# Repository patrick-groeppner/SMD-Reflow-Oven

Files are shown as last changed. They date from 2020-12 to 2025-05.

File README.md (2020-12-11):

# SMD-Reflow-Oven
files and pictures for the selfmade SMD reflow oven. Made with an Arduino as a PID controller, a thermocouple sensor for fast and high range measurements and a solid state relay for switching an mini oven on and off

capable of:
- reflow soldering with different profiles / manual set temperature
- heating pcb clads with photoresist lacquer: temp curve and manual set temperature

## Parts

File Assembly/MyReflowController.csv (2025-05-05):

Designator | Quantity | Comment | Footprint | LCSC Part #
C1, C2, C4, C6, C8, C12, C13, C15, C16, C18, | 10 | 100nF | 0603 | C14663
C3, | 1 | 1uF | 0805 | C28323
C5, | 1 | 30pF | 0603 | C22397
C7, C10, | 2 | 10nF | 0603 | C57112
C9, | 1 | 30pF | 0603 | C22397
C11, C14, | 2 | 10uF | 0805 | C15850
C17, | 1 | 100nF | 0805 | C14663
D1, | 1 | Red | 0805 | C84256
D2, D3, | 2 | Green | 0603 | C72043
FB1, | 1 | Ferrit | 0805 | C1017
Q1, | 1 | SS8050 | SOT-23-3 | C2150
Q2, Q3, | 2 | AO3400A | SOT-23-3L | C20917
R1, R2, | 2 | 2K2 | 0603 | C4190
R3, R4, R6, R12, | 4 | 10k | 0805 | C17414
R5, | 1 | 100R | 1206 | C17901
R7, R8, R9, | 3 | 10K | 1206 | C17902
R10, R11, R15, | 3 | 1K | 0603 | C21190
R13, R14, | 2 | 100R | 0603 | C22775
U1, | 1 | ATMEGA328P | TQFP-32_7.0x7.0x0.8P | C14877
U2, | 1 | MAX6675 | SOIC-8_3.9x4.9x1.27P | C16030
U3, | 1 | AMS1117-3.3 | SOT-223 | C6186
U4, | 1 | CH340E | MSOP-10_3.0x3.0x0.5P | C99652
Y1, | 1 | 8MHz | SMD-5032_2P | C115962

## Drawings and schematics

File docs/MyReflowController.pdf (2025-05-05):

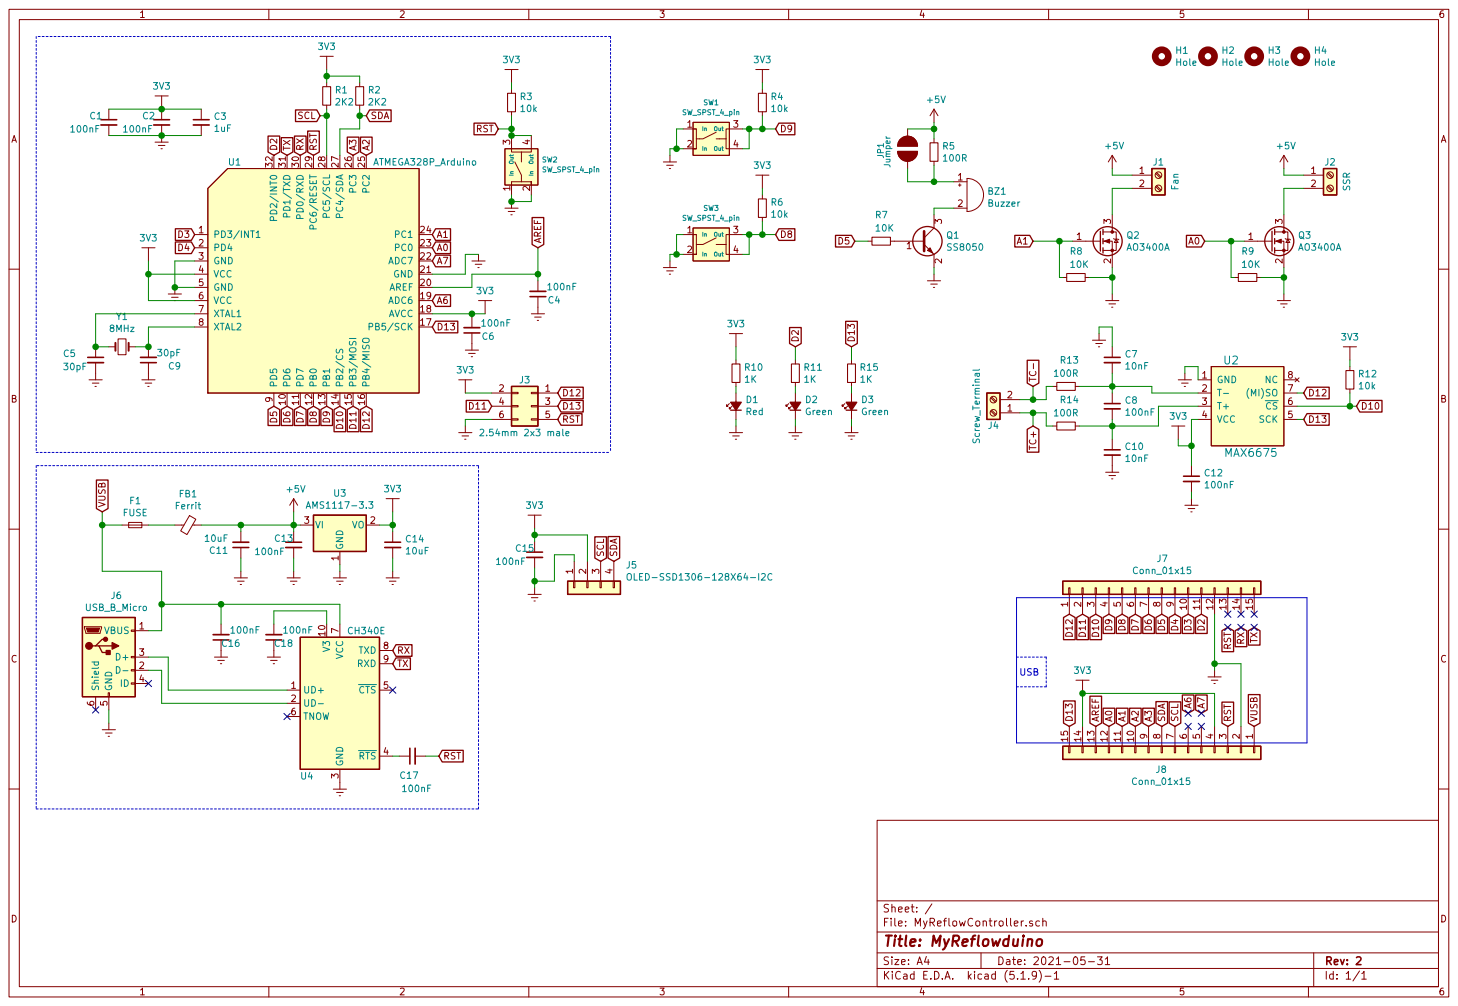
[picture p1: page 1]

3 RTS 4 CTS 5 TNOW 6 VCC

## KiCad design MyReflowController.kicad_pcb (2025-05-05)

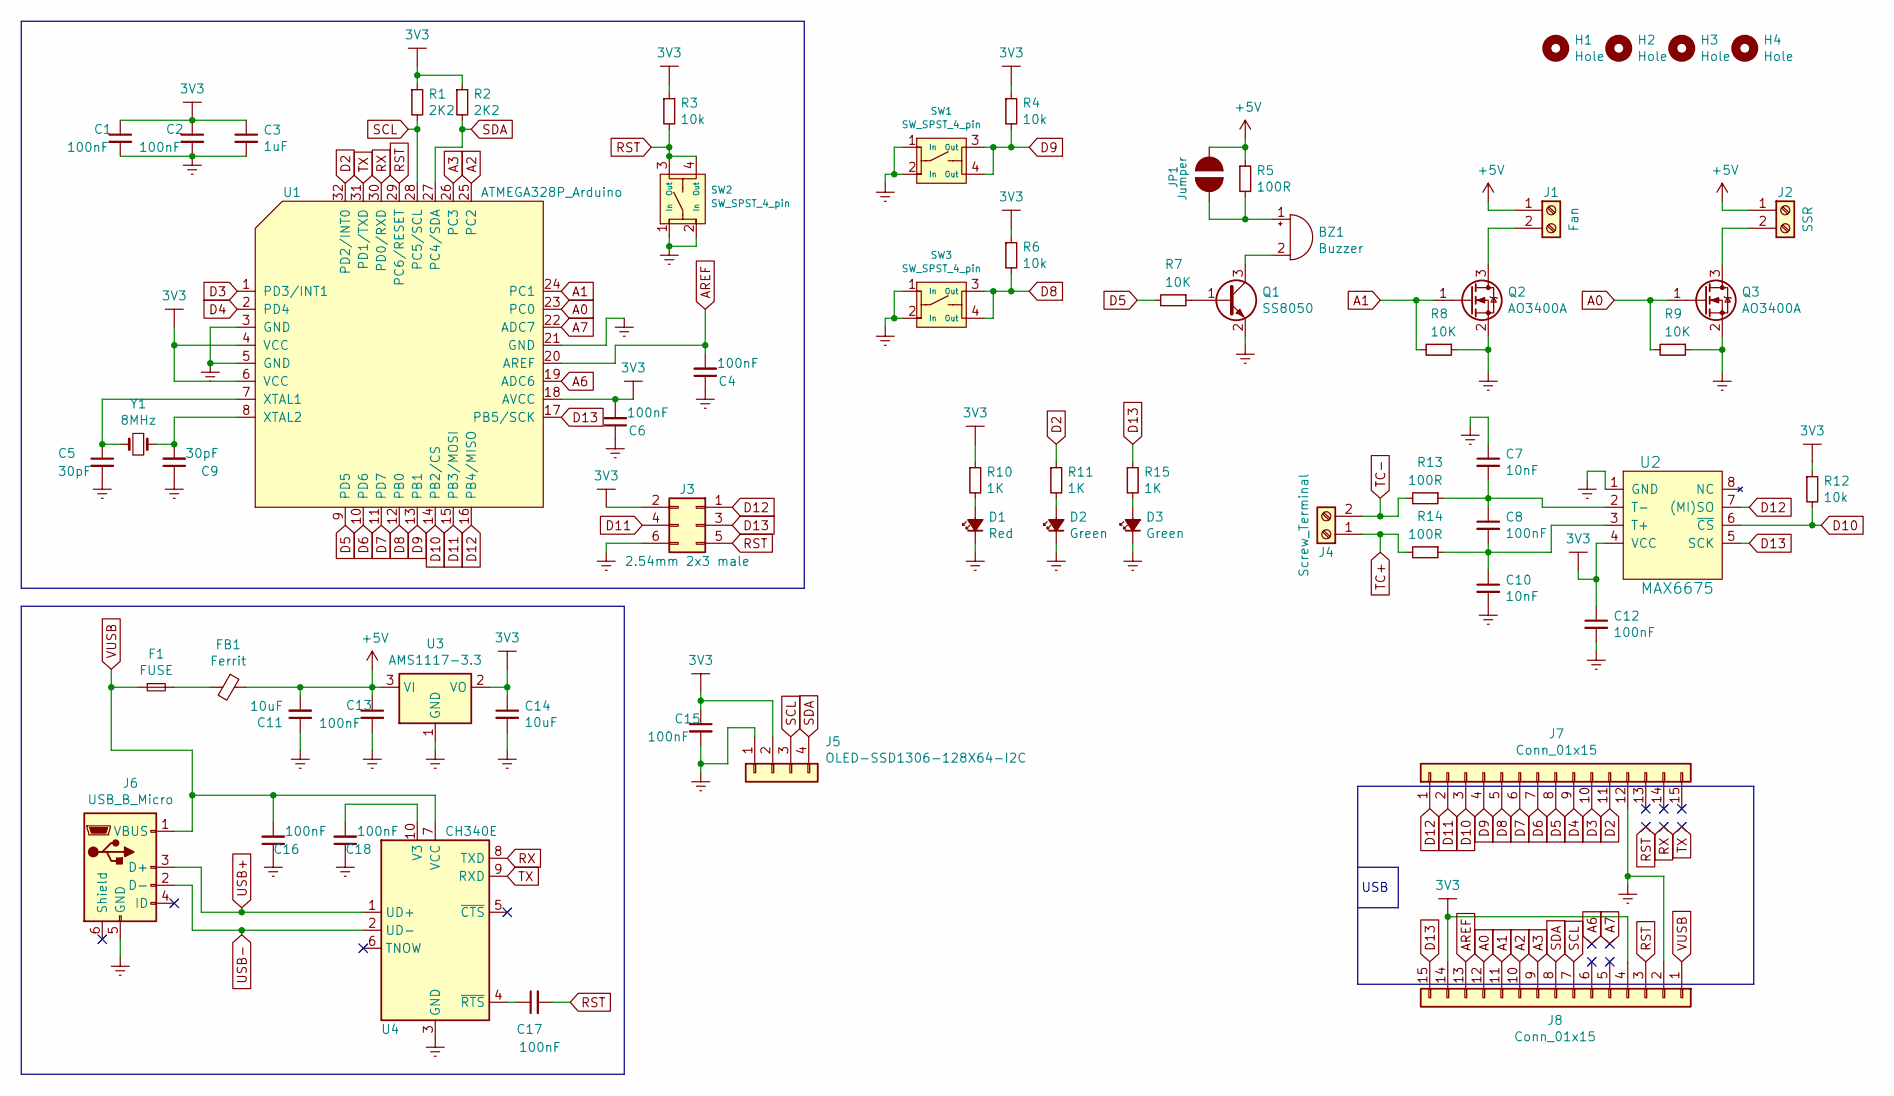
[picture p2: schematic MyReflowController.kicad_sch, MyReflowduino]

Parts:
BZ1: Buzzer; Buzzer_12x9.5RM7.6
C1, C2, C4, C6, C8, C12, C13, C15, C16, C18: 100nF; C_0603_1608Metric_Pad1.08x0.95mm_HandSolder; Part# C14663
C3: 1uF; C_0805_2012Metric_Pad1.18x1.45mm_HandSolder; Part# C28323
C5, C9: 30pF; C_0603_1608Metric; Part# C22397
C7, C10: 10nF; C_0603_1608Metric_Pad1.08x0.95mm_HandSolder; Part# C57112
C11, C14: 10uF; C_0805_2012Metric_Pad1.18x1.45mm_HandSolder; Part# C15850
C17: 100nF; C_0805_2012Metric_Pad1.18x1.45mm_HandSolder; Part# C14663
D1: Red; LED_0805_2012Metric_Pad1.15x1.40mm_HandSolder; Part# C84256
D2, D3: Green; LED_0603_1608Metric_Pad1.05x0.95mm_HandSolder; Part# C72043
F1: FUSE; Fuse_1206_3216Metric_Pad1.42x1.75mm_HandSolder
FB1: Ferrit; Fuse_0805_2012Metric_Pad1.15x1.40mm_HandSolder; Part# C1017
H1, H2, H3, H4: Hole; MountingHole_3.2mm_M3
J1: Fan; TerminalBlock_bornier-2_P5.08mm
J2: SSR; TerminalBlock_bornier-2_P5.08mm
J3: 2.54mm 2x3 male; PinSocket_2x03_P2.54mm_Vertical
J4: Screw_Terminal; TerminalBlock_bornier-2_P5.08mm
J5: OLED-SSD1306-128X64-I2C; OLED-SSD1306-128X64-THT
J6: USB_B_Micro; 111A1010D10200_USB-2.0_THT
J7, J8: Conn_01x15; PinHeader_1x15_P2.54mm_Vertical
JP1: Jumper; SolderJumper-2_P1.3mm_Bridged_Pad1.0x1.5mm
Q1: SS8050; SOT-23-3; Part# C2150
Q2, Q3: AO3400A; SOT-23; Part# C20917
R1, R2: 2K2; R_0603_1608Metric_Pad0.98x0.95mm_HandSolder; Part# C4190
R3, R4, R6, R12: 10k; R_0805_2012Metric_Pad1.20x1.40mm_HandSolder; Part# C17414
R5: 100R; R_1206_3216Metric_Pad1.30x1.75mm_HandSolder; Part# C17901
R7, R8, R9: 10K; R_1206_3216Metric_Pad1.30x1.75mm_HandSolder; Part# C17902
R10, R11, R15: 1K; R_0603_1608Metric_Pad0.98x0.95mm_HandSolder; Part# C21190
R13, R14: 100R; R_0603_1608Metric; Part# C22775
SW1, SW2, SW3: SW_SPST_4_pin; TACTILE_SWITCH_PTH_6.0MM
U1: ATMEGA328P_Arduino; TQFP-32_7x7mm; Part# C14877
U2: MAX6675; SOIC-8_W3.9mm; Part# C16030
U3: AMS1117-3.3; SOT-223-3_TabPin2; Part# C6186
U4: CH340E; MSOP-10_3x3mm_P0.5mm; Part# C99652
Y1: 8MHz; Crystal_SMD_TXC_7A-2Pin_5x3.2mm; Part# C115962

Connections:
3V3: C1.1, C2.1, C3.1, C6.2, C12.1, C14.1, C15.1, J3.2, J5.2, J8.4, J8.14, R1.1, R2.1, R3.1, R4.1, R6.1, R10.1, R12.1, U1.4 (VCC), U1.6 (VCC), U1.18 (AVCC), U2.4 (VCC), U3.2 (VO)
+5V: C11.2, C13.1, FB1.1, J1.1, J2.1, JP1.1, R5.1, U3.3 (VI)
A0: J8.12, Q3.1 (G), R9.2, U1.23 (PC0)
A1: J8.11, Q2.1 (G), R8.2, U1.24 (PC1)
A2: J8.10, U1.25 (PC2)
A3: J8.9, U1.26 (PC3)
A6: U1.19 (ADC6)
A7: U1.22 (ADC7)
AREF: C4.2, J8.13, U1.20 (AREF)
D2: J7.11, R11.1, U1.32 (PD2/INT0)
D3: J7.10, U1.1 (PD3/INT1)
D4: J7.9, U1.2 (PD4)
D5: J7.8, R7.2, U1.9 (PD5)
D6: J7.7, U1.10 (PD6)
D7: J7.6, U1.11 (PD7)
D8: J7.5, R6.2, SW3.3 (Out), SW3.4 (Out), U1.12 (PB0)
D9: J7.4, R4.2, SW1.3 (Out), SW1.4 (Out), U1.13 (PB1)
D10: J7.3, R12.2, U1.14 (PB2/CS), U2.6 (~CS)
D11: J3.4, J7.2, U1.15 (PB3/MOSI)
D12: J3.1, J7.1, U1.16 (PB4/MISO), U2.7 ((MI)SO)
D13: J3.3, J8.15, R15.1, U1.17 (PB5/SCK), U2.5 (SCK)
Masse: C1.2, C2.2, C3.2, C4.1, C5.2, C6.1, C7.1, C9.1, C10.2, C11.1, C12.2, C13.2, C14.2, C15.2, C16.1, C18.1, D1.1 (K), D2.1 (K), D3.1 (K), J3.6, J5.1, J6.5 (GND), J7.12, J8.2, Q1.2 (E), Q2.2 (S), Q3.2 (S), R8.1, R9.1, SW1.1 (In), SW1.2 (In), SW2.1 (In), SW2.2 (In), SW3.1 (In), SW3.2 (In), U1.3 (GND), U1.5 (GND), U1.21 (GND), U2.1 (GND), U3.1 (GND), U4.3 (GND)
unnamed: BZ1.1 (-), JP1.2, R5.2
unnamed: BZ1.2 (+), Q1.3 (C)
unnamed: C5.1, U1.7 (XTAL1), Y1.2
unnamed: C7.2, C8.1, R13.1, U2.2 (T-)
unnamed: C9.2, U1.8 (XTAL2), Y1.1
unnamed: C8.2, C10.1, R14.1, U2.3 (T+)
unnamed: C17.1, U4.4 (~RTS)
unnamed: C18.2, U4.10 (V3)
unnamed: D1.2 (A), R10.2
unnamed: D2.2 (A), R11.2
unnamed: D3.2 (A), R15.2
unnamed: F1.2, FB1.2
unnamed: J1.2, Q2.3 (D)
unnamed: J2.2, Q3.3 (D)
unnamed: Q1.1 (B), R7.1
RST: C17.2, J3.5, J8.3, R3.2, SW2.3 (Out), SW2.4 (Out), U1.29 (PC6/RESET)
RX: U1.30 (PD0/RXD), U4.8 (TXD)
SCL: J5.3, J8.7, R1.2, U1.28 (PC5/SCL)
SDA: J5.4, J8.8, R2.2, U1.27 (PC4/SDA)
TC+: J4.1, R14.2
TC-: J4.2, R13.2
TX: U1.31 (PD1/TXD), U4.9 (RXD)
USB+: J6.3 (D+), U4.1 (UD+)
USB-: J6.2 (D-), U4.2 (UD-)
VUSB: C16.2, F1.1, J6.1 (VBUS), J8.1, U4.7 (VCC)

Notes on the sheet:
USB

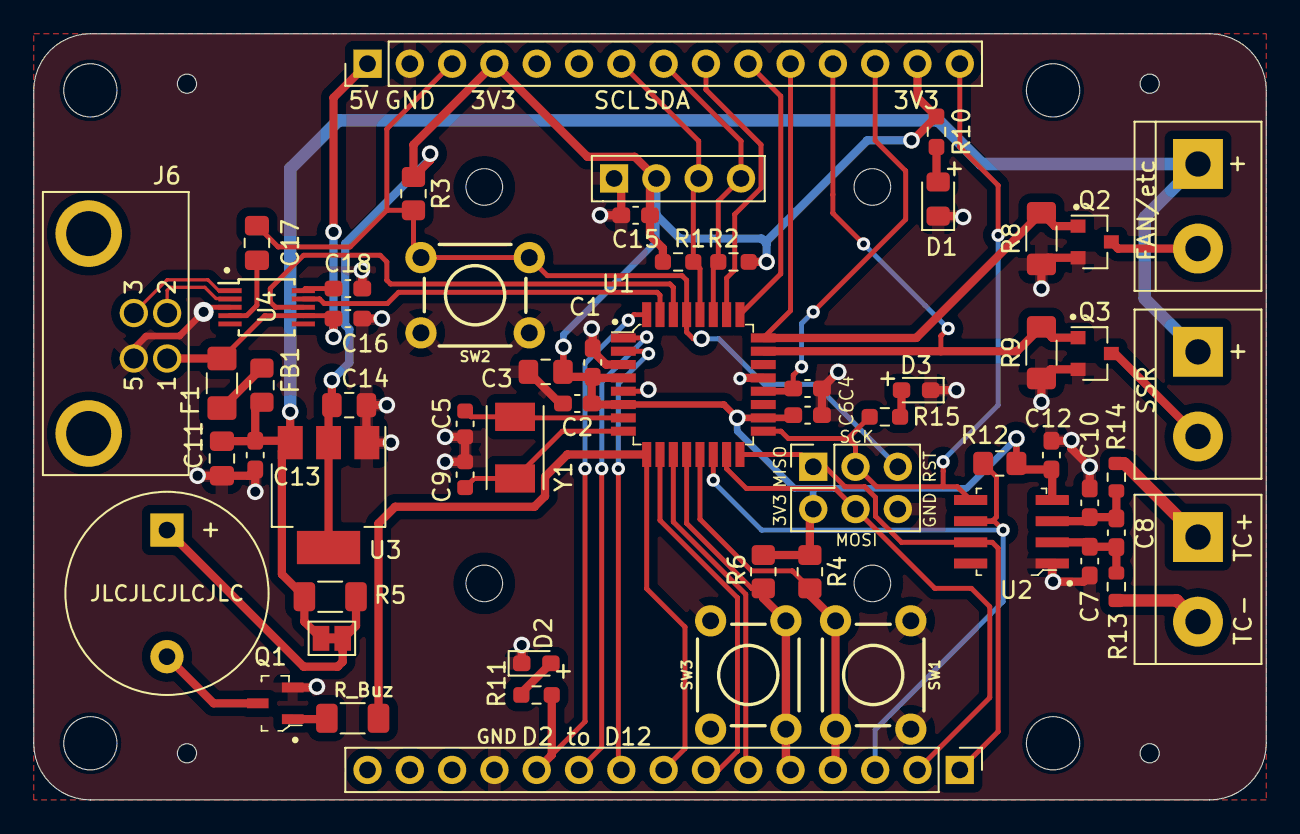
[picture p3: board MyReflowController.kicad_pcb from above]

Board: 2 copper layers, 74.0 x 46.0 mm, 63 parts (0 on the bottom side), 45 nets.
